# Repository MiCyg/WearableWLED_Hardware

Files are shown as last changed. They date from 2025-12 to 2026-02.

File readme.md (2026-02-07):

# Wearable WLED Hardware


[← Back to main repository](https://github.com/MiCyg/WearableWLED.git)

---

This PCB combines an ESP32‑C3 Mini with a battery charger, a power switch, and a USB‑C connector for power and programming. All components are low‑cost and readily available. The PCB measures 20×40 mm, allowing a compact enclosure and battery.

<p align="center">
	
</p>

<p align="center">
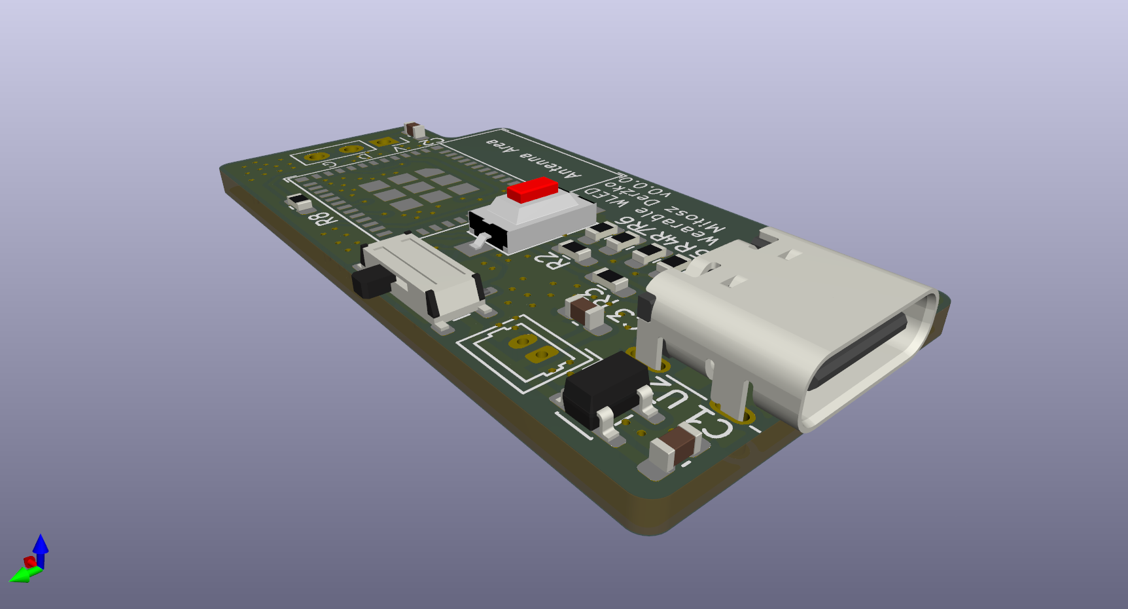
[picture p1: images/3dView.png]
	
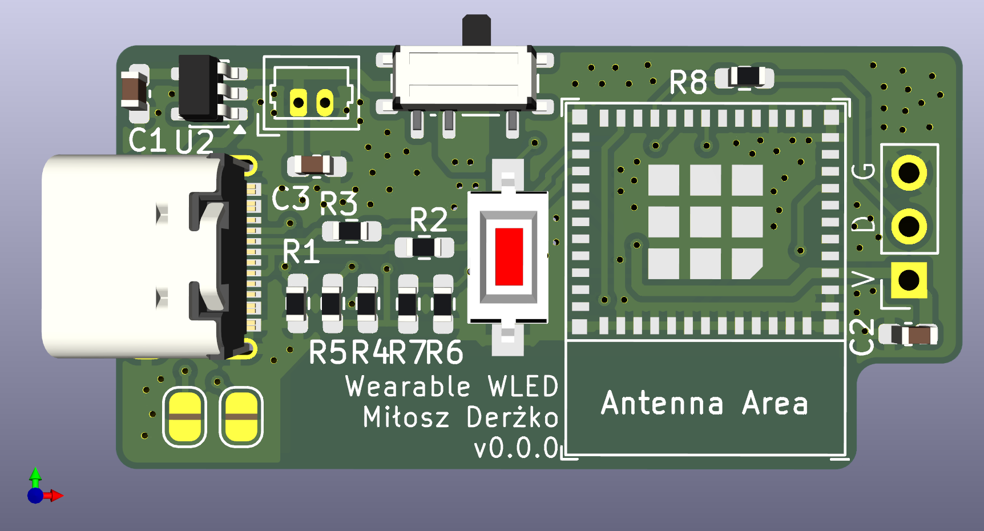
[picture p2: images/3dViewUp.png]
	
</p>

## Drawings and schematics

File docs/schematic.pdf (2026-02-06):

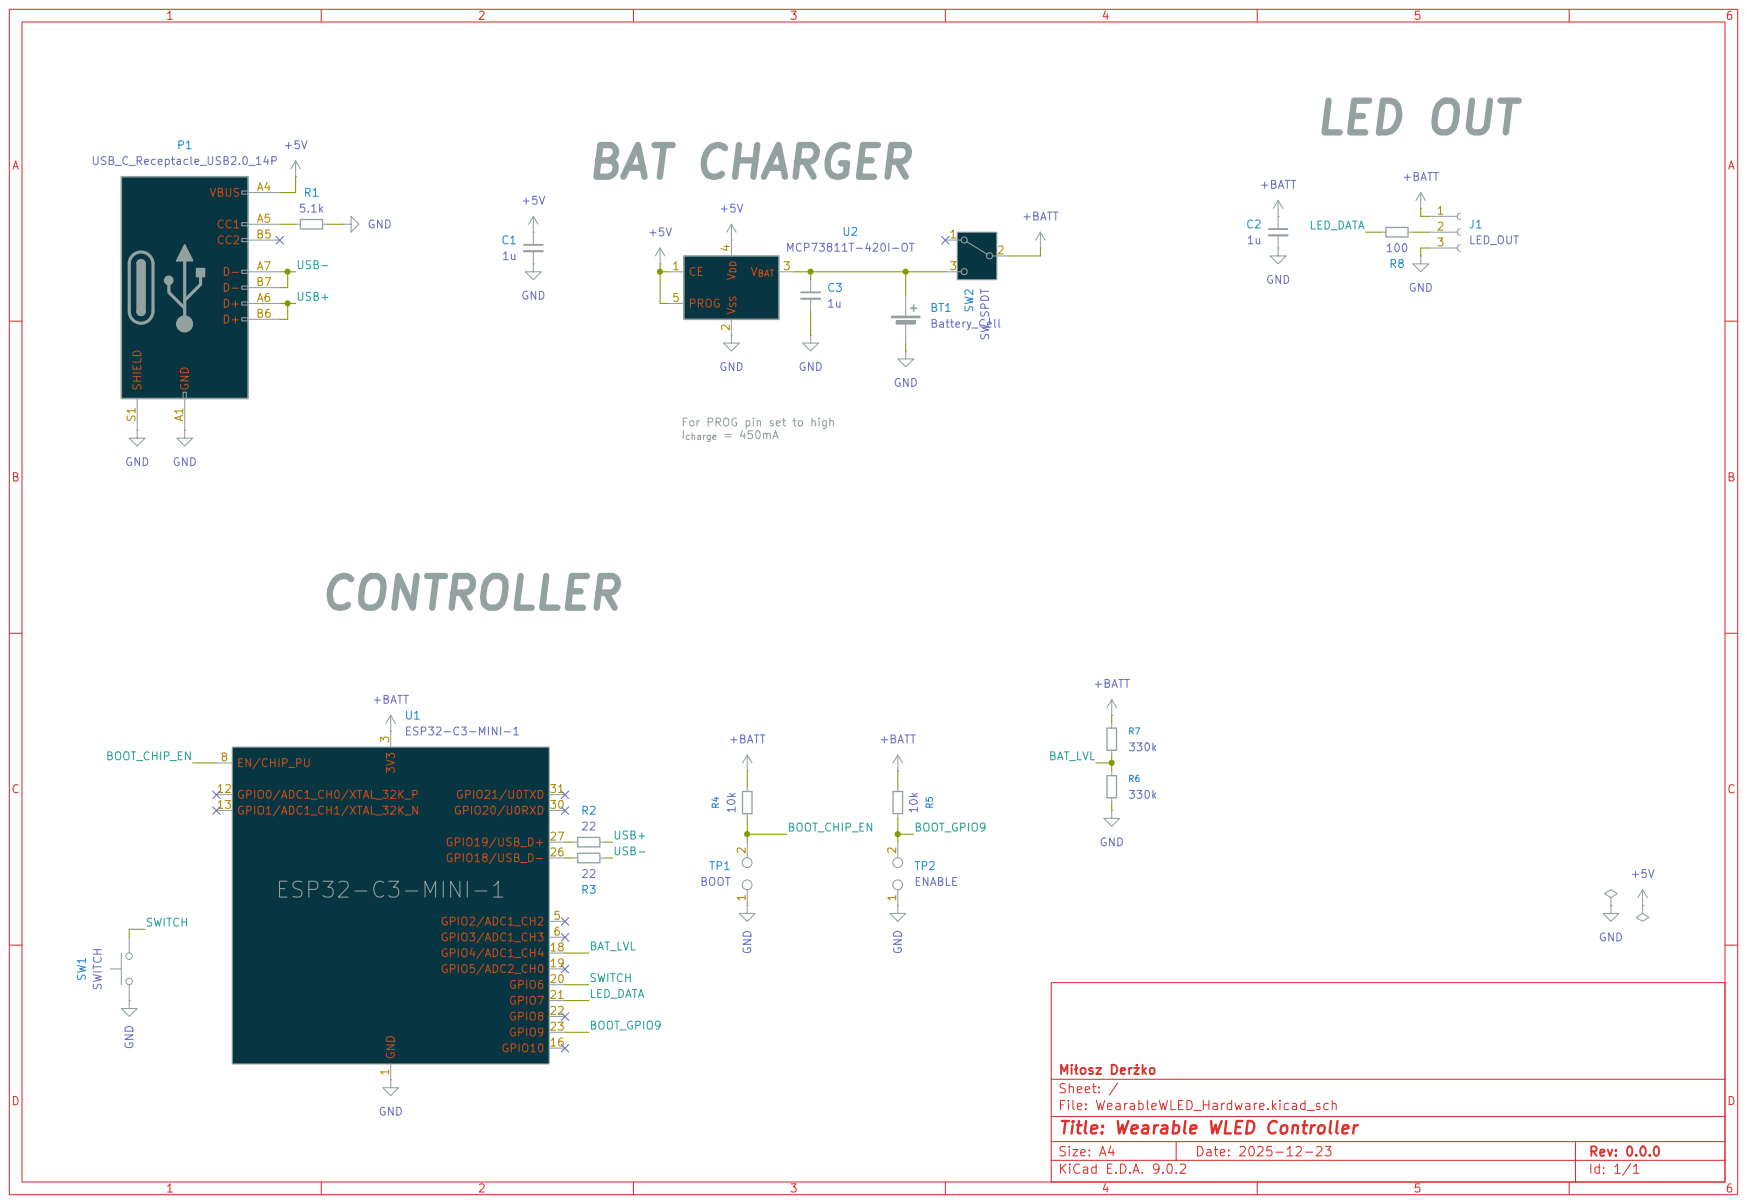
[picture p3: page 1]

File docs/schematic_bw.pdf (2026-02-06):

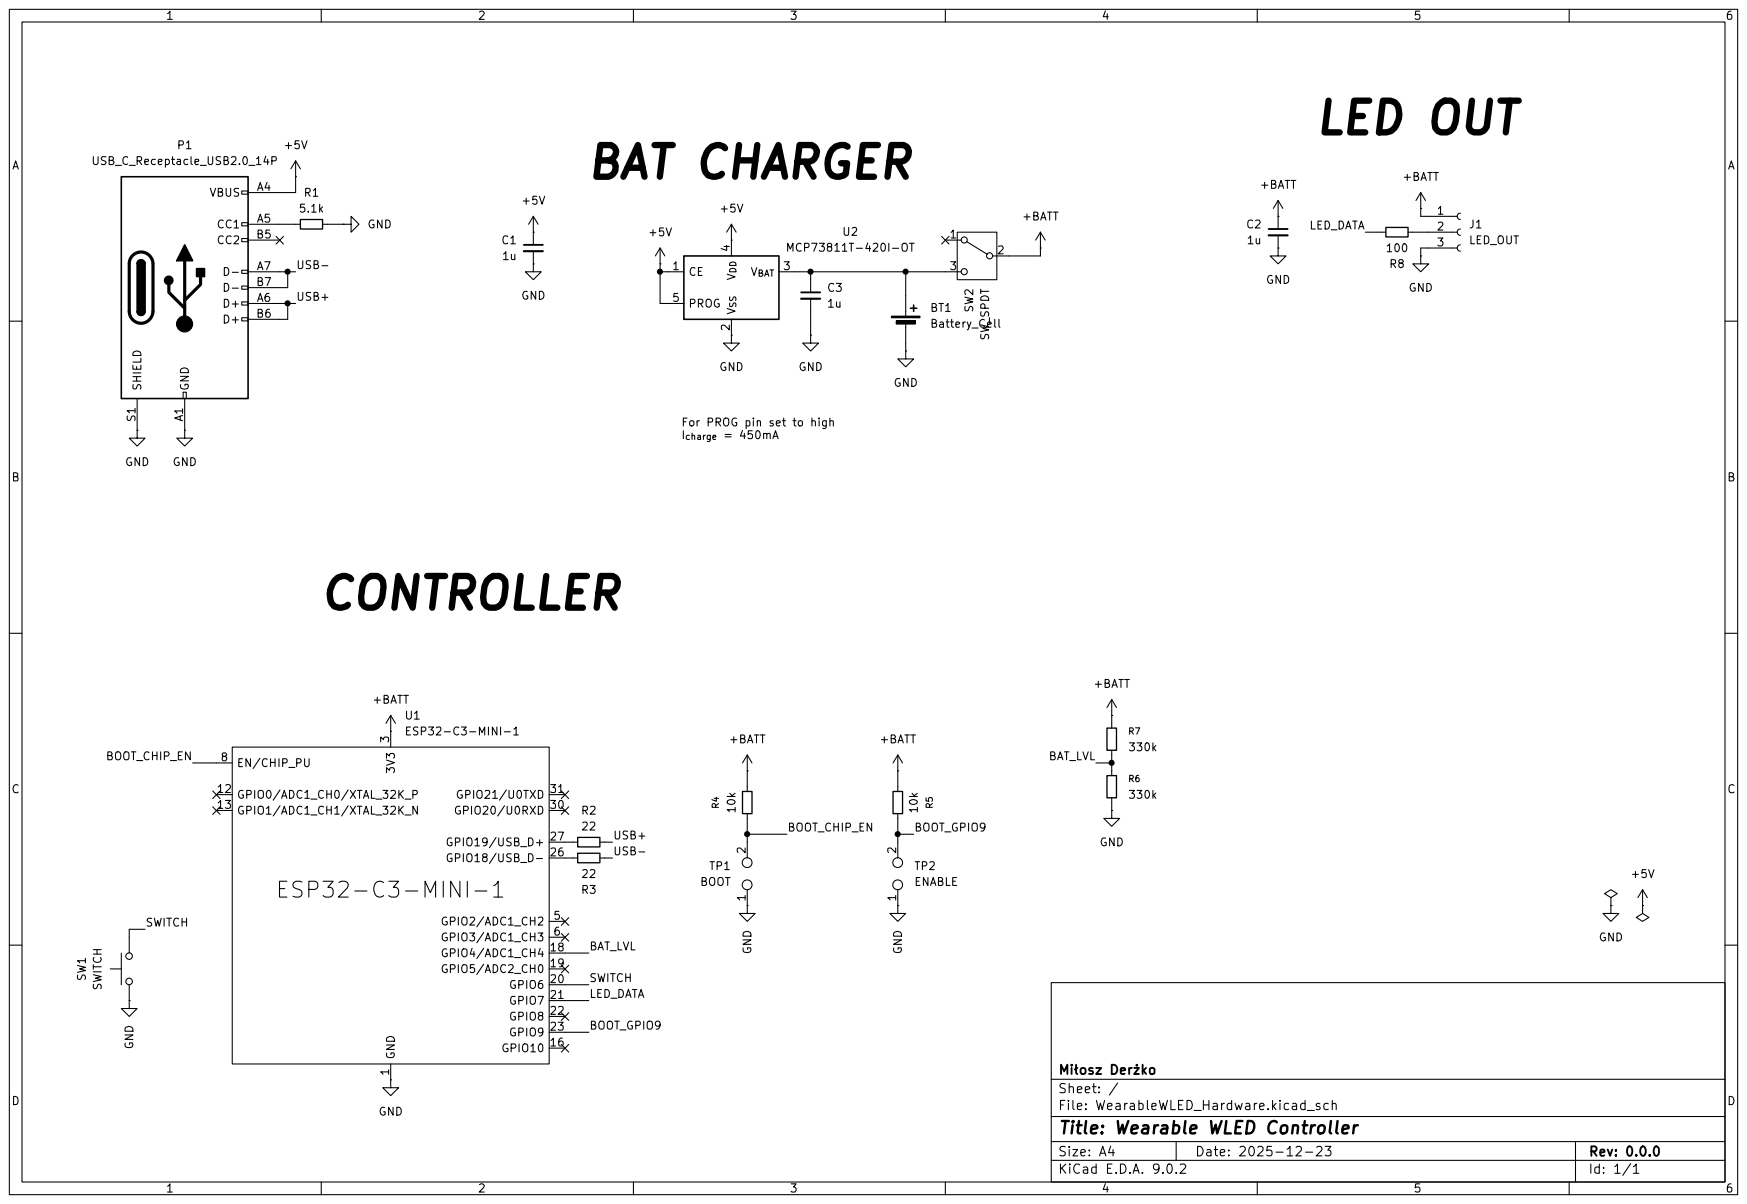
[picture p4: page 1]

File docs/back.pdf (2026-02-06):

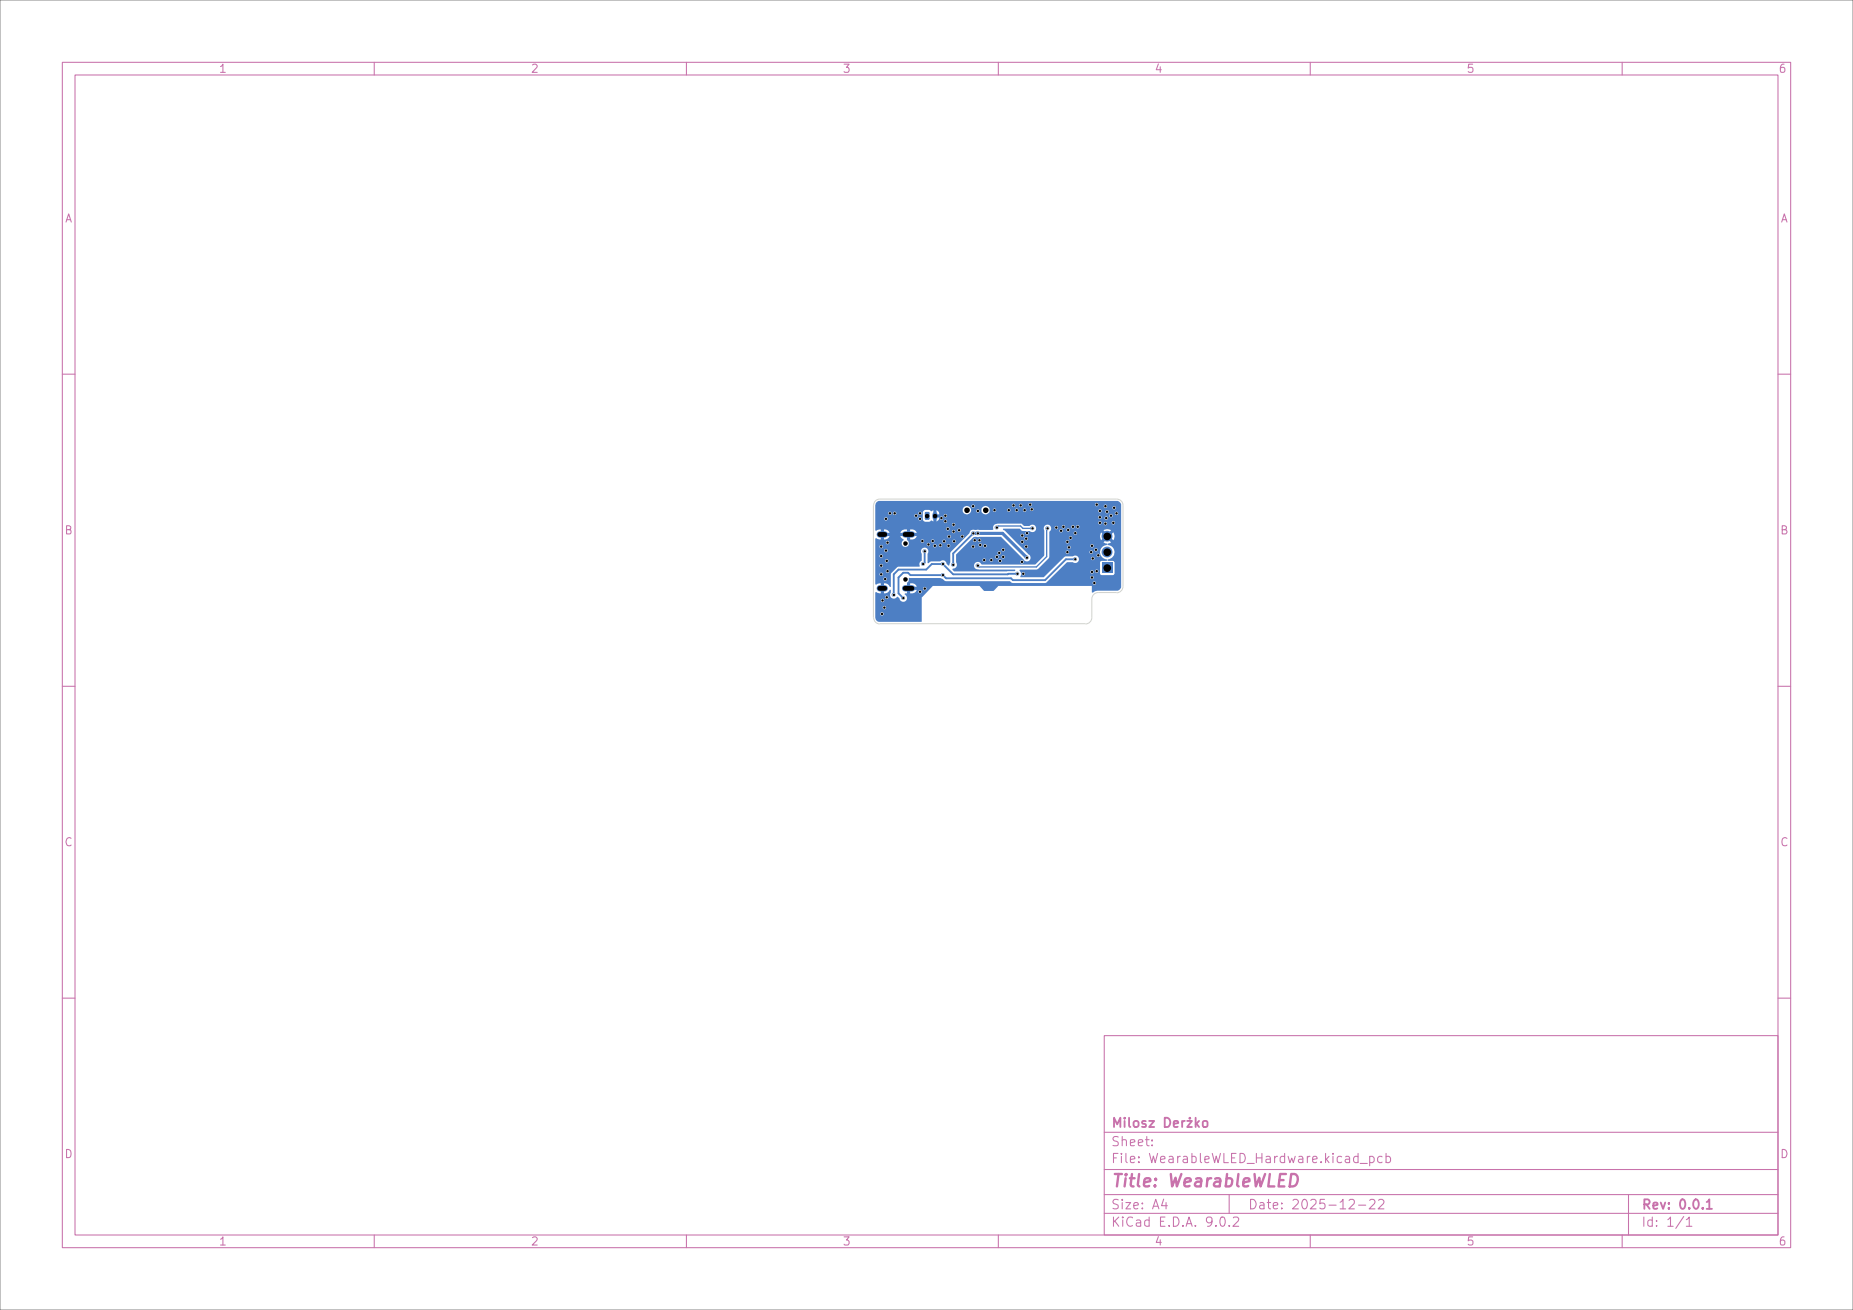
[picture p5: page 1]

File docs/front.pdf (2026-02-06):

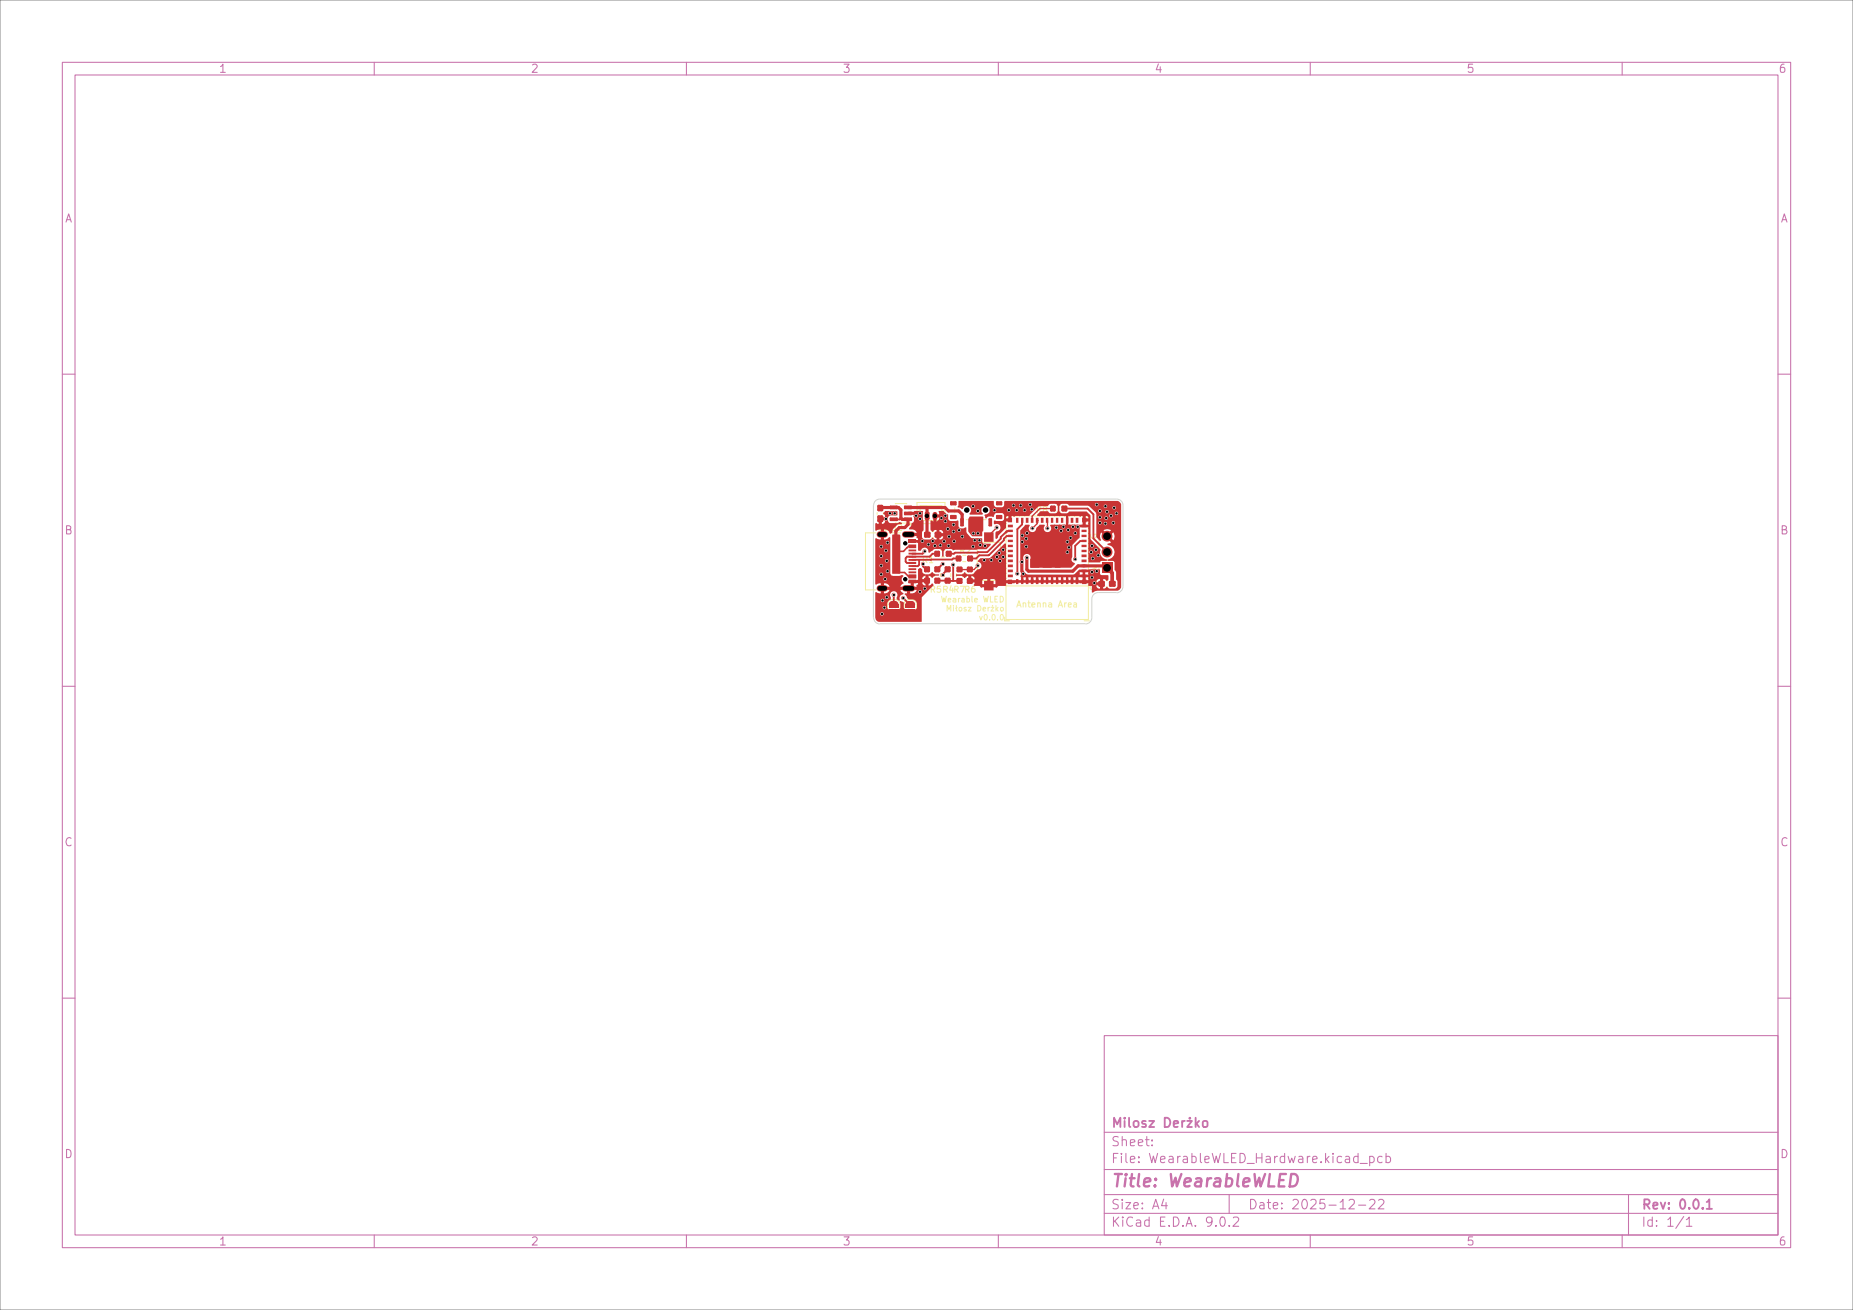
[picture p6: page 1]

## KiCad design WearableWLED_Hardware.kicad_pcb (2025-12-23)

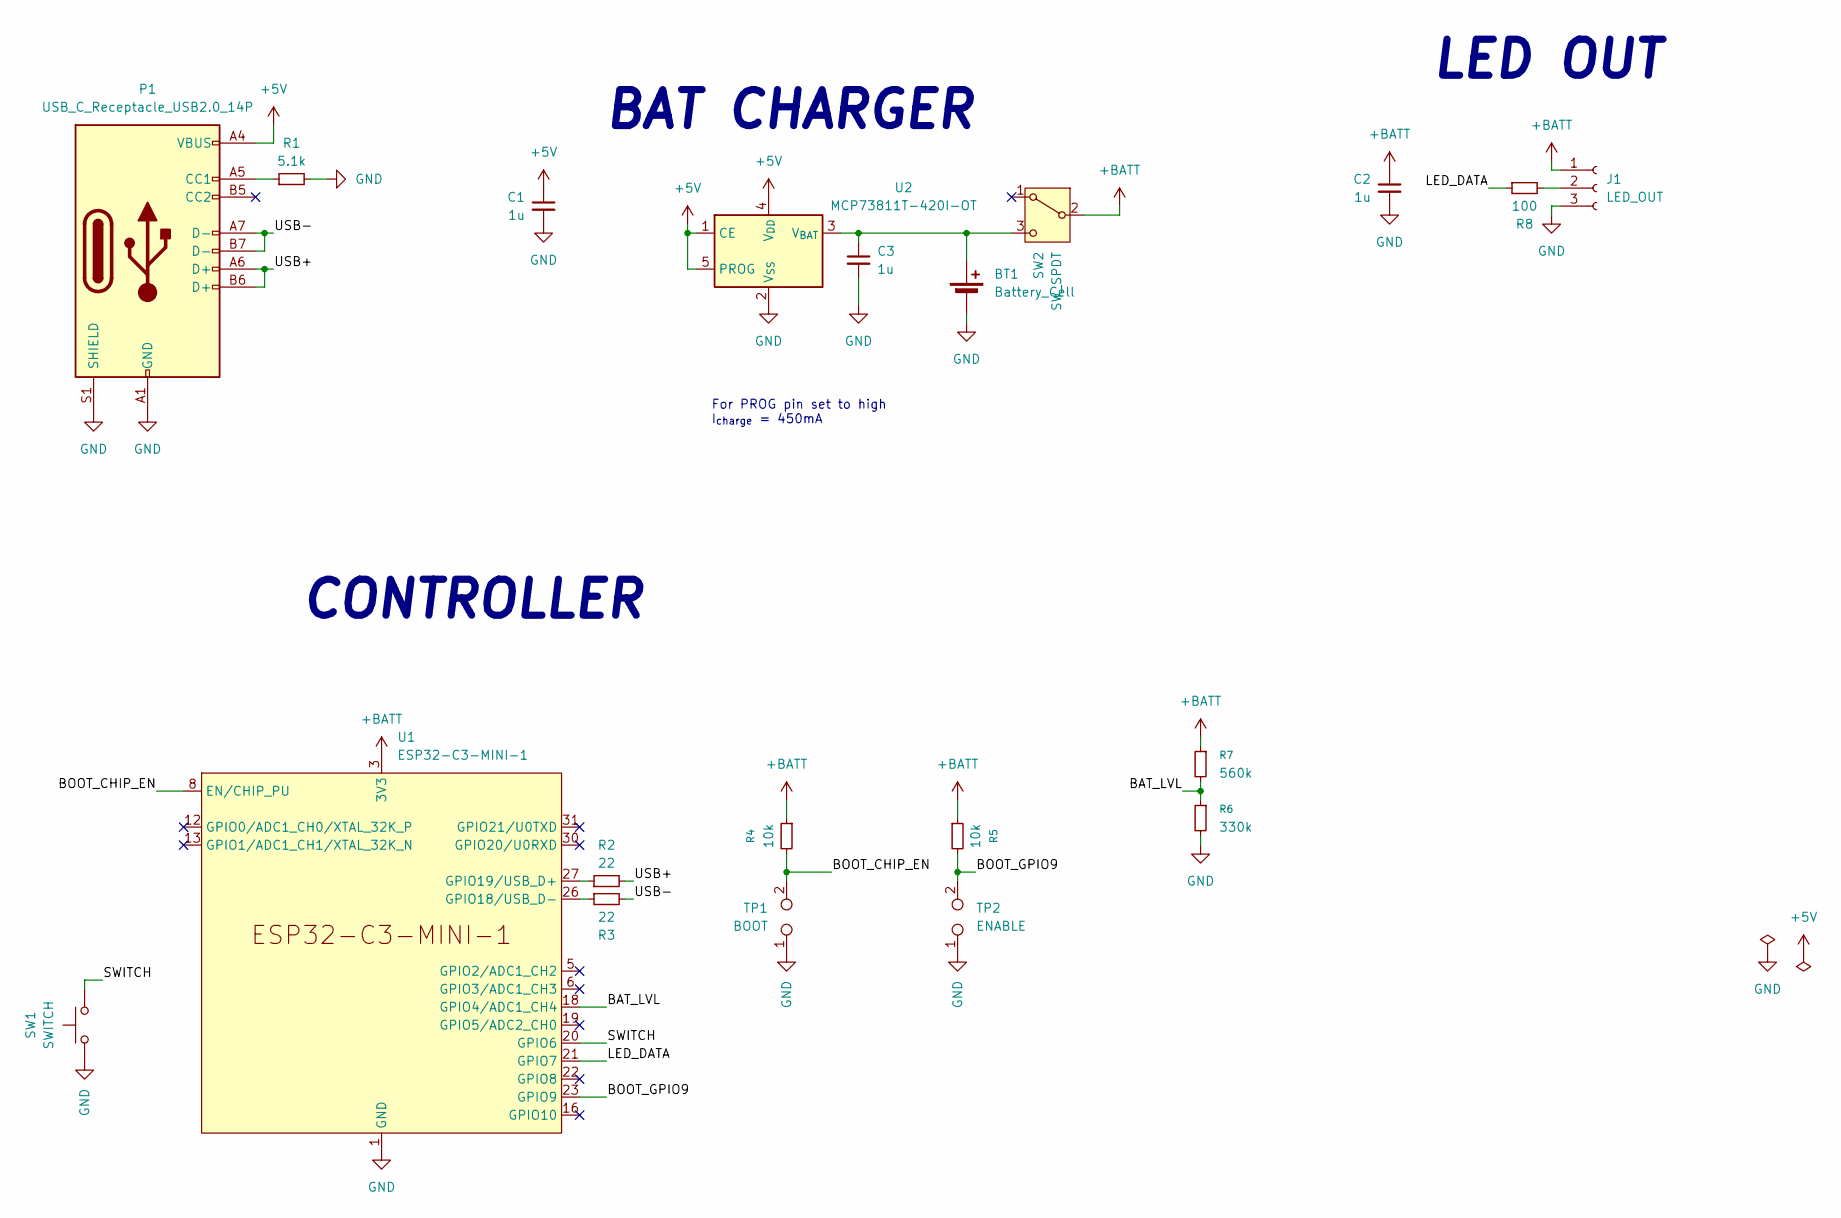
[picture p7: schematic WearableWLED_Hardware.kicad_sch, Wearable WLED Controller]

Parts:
BT1: Battery_Cell; Molex_PicoBlade_53047-0210_1x02_P1.25mm_Vertical
C1, C2, C3: 1u; C_0603_1608Metric_Pad1.08x0.95mm_HandSolder
J1: LED_OUT; PinSocket_1x03_P2.54mm_Vertical
P1: USB_C_Receptacle_USB2.0_14P; USB_C_Receptacle_G-Switch_GT-USB-7010ASV
R1: 5.1k; R_0603_1608Metric_Pad0.98x0.95mm_HandSolder
R2, R3: 22; R_0603_1608Metric_Pad0.98x0.95mm_HandSolder
R4, R5: 10k; R_0603_1608Metric_Pad0.98x0.95mm_HandSolder
R6: 330k; R_0603_1608Metric_Pad0.98x0.95mm_HandSolder
R7: 560k; R_0603_1608Metric_Pad0.98x0.95mm_HandSolder
R8: 100; R_0603_1608Metric_Pad0.98x0.95mm_HandSolder
SW1: SWITCH; SW_SPST_CK_RS282G05A3
SW2: SW_SPDT; SW_SPDT_Shouhan_MSK12C02
TP1: BOOT; SolderJumper-2_P1.3mm_Open_RoundedPad1.0x1.5mm
TP2: ENABLE; SolderJumper-2_P1.3mm_Open_RoundedPad1.0x1.5mm
U1: ESP32-C3-MINI-1
U2: MCP73811T-420I-OT; SOT-23-5

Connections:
+5V: C1.1, P1.A4 (VBUS), P1.A9 (VBUS), P1.B4 (VBUS), P1.B9 (VBUS), U2.1 (CE), U2.4 (V_{DD}), U2.5 (PROG)
+BATT: C2.1, J1.1, R4.1, R5.1, R7.1, SW2.2 (B), U1.3 (3V3)
/BAT_LVL: R6.1, R7.2, U1.18 (GPIO4/ADC1_CH4)
/BOOT_CHIP_EN: R4.2, TP1.2, U1.8 (EN/CHIP_PU)
/BOOT_GPIO9: R5.2, TP2.2, U1.23 (GPIO9)
/LED_DATA: R8.1, U1.21 (GPIO7)
/SWITCH: SW1.2, U1.20 (GPIO6)
/USB+: P1.A6 (D+), P1.B6 (D+), R2.2
/USB-: P1.A7 (D-), P1.B7 (D-), R3.2
GND: BT1.2 (-), C1.2, C2.2, C3.2, J1.3, P1.A1 (GND), P1.A12 (GND), P1.B1 (GND), P1.B12 (GND), P1.S1 (SHIELD), R1.2, R6.2, SW1.1, TP1.1, TP2.1, U1.1 (GND), U1.2 (GND), U1.11 (GND), U1.14 (GND), U1.36 (GND), U1.37 (GND), U1.38 (GND), U1.39 (GND), U1.40 (GND), U1.41 (GND), U1.42 (GND), U1.43 (GND), U1.44 (GND), U1.45 (GND), U1.46 (GND), U1.47 (GND), U1.48 (GND), U1.49 (GND), U1.50 (GND), U1.51 (GND), U1.52 (GND), U1.53 (GND), U2.2 (V_{SS})
unnamed: BT1.1 (+), C3.1, SW2.3 (C), U2.3 (V_{BAT})
unnamed: J1.2, R8.2
unnamed: P1.A5 (CC1), R1.1
unnamed: R3.1, U1.26 (GPIO18/USB_D-)
unnamed: R2.1, U1.27 (GPIO19/USB_D+)

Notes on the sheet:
LED OUT
For PROG pin set to high I_{charge} = 450mA
CONTROLLER
BAT CHARGER

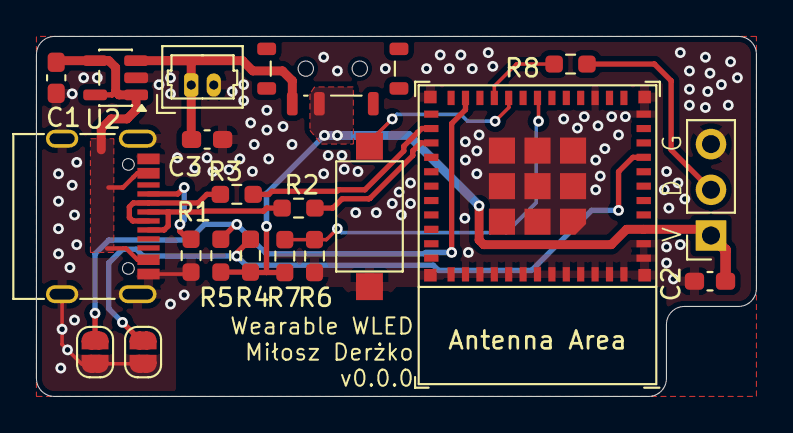
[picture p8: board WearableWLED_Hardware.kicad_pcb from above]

Board: 2 copper layers, 40.0 x 20.0 mm, 20 parts (0 on the bottom side), 15 nets.

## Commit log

2025-12-23 chore: init repo
    [WearableWLED_Hardware.kicad_pcb, WearableWLED_Hardware.kicad_sch]
2026-02-06 Change voltage divider value for battery
    [WearableWLED_Hardware.kicad_sch]
